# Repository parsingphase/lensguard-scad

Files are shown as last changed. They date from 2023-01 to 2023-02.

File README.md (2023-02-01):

# 3D-printable lens switch guards for various DSLR / Mirrorless camera lenses

[STL](https://en.wikipedia.org/wiki/STL_(file_format)) printable files and [OpenSCAD](https://openscad.org) working files.

Note that these designs are prototypes and have not been used in the field yet.
Also, don't assume that the `.stl` files are correctly updated from the `.scad` files.

## Available guards

STL links will display the file in an interactive viewer.

### Canon RF 800mm f/11 IS STM Lens

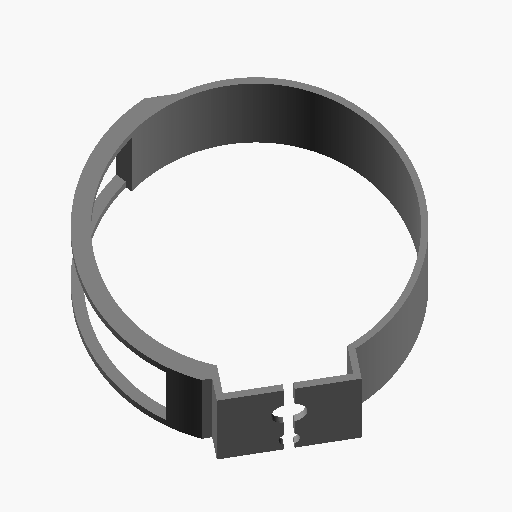
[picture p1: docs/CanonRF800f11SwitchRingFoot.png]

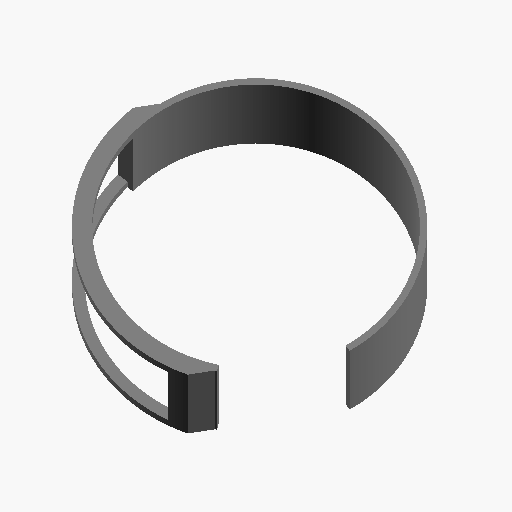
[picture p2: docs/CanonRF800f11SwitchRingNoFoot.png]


This lens has a tripod mounting foot (of sorts) in the same ring segment as the switches.
As such there are two prototypes for this lens, one that omits the foot mounting entirely,
with the intent that it'll be mounted with dual-sided adhesive tape, and one that tries to 
use the foot mount to hold the lens in place. Note that this will interfere with the mount;
best case is you'll likely need a longer mounting screw, worst case is your camera isn't as
secure on your tripod. All use of these designs is at your own risk.

Another fun aspect of this lens is that the ring segment is not flat, so fit is best-effort.

* Mount with foot: [STL](CanonRF800f11SwitchRingFoot.stl), [SCAD](CanonRF800f11SwitchRingFoot.scad)
* Mount without foot: [STL](CanonRF800f11SwitchRingNoFoot.stl), [SCAD](CanonRF800f11SwitchRingNoFoot.scad)

### Sigma 150-600mm f/5-6.3 DG OS HSM Contemporary Lens for Canon EF
### Sigma 100-400mm f/5-6.3 DG OS HSM Contemporary Lens for Canon EF

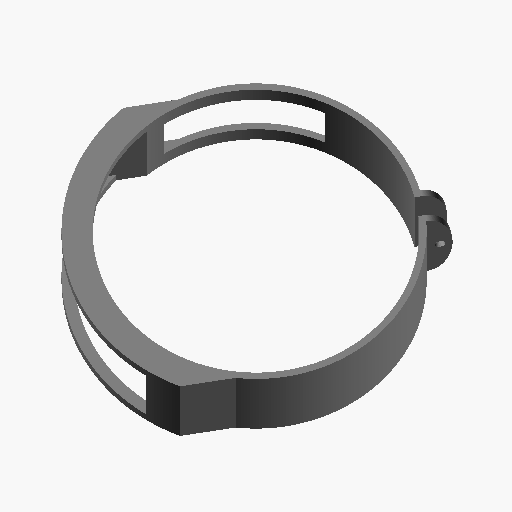
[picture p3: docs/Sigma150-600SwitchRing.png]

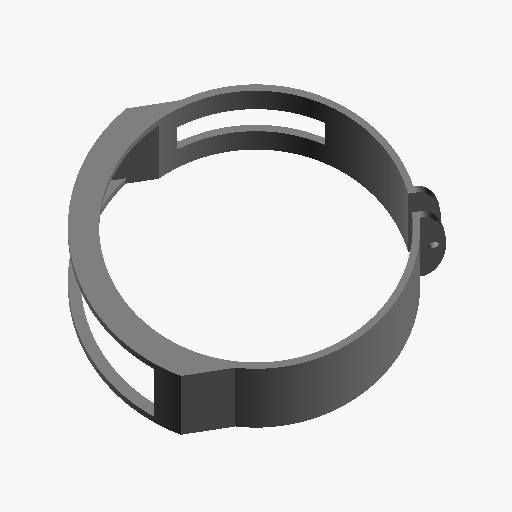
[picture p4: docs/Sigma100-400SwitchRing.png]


These lenses are a very similar design; the lens segments are unobstructed by any foot mount 
and have a flat cross-section. Current designs have a fitting for a #4 closure bolt opposite the switch window.

* 150-600: [STL](Sigma150-600SwitchRing.stl), [SCAD](Sigma150-600SwitchRing.scad)
* 100-400: [STL](Sigma100-400SwitchRing.stl), [SCAD](Sigma100-400SwitchRing.scad)

## Printed rings

Printed in ABS by Taurus 3D via [CraftCloud3D](https://craftcloud3d.com/). I've not fit the other guards yet.

### Canon RF 800mm f/11 IS STM Lens

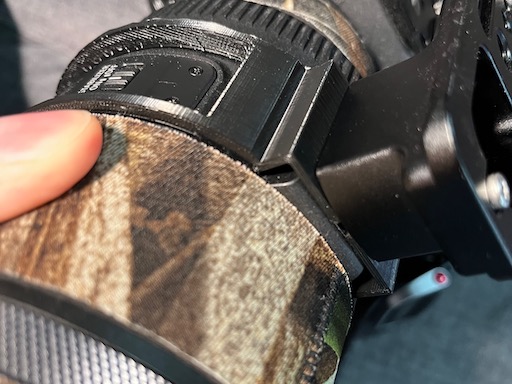
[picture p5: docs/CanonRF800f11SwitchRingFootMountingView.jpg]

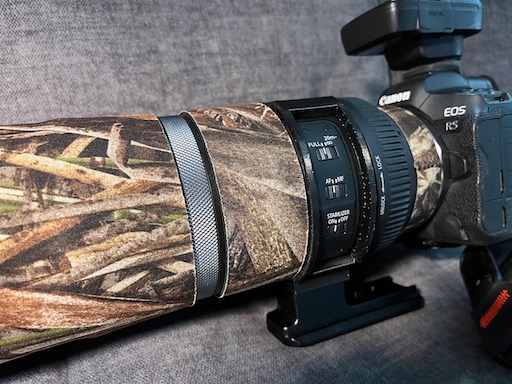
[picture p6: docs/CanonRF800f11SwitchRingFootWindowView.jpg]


### Sigma 150-600mm f/5-6.3 Lens

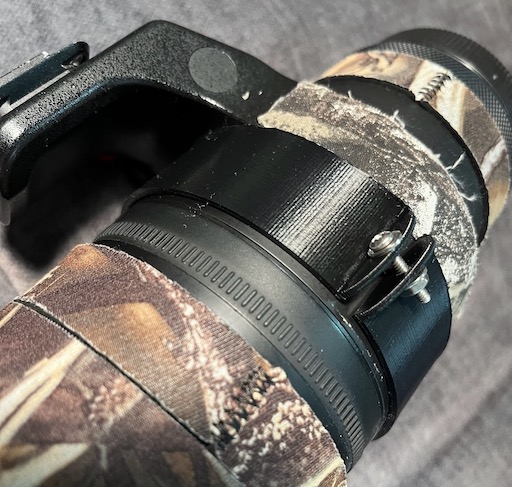
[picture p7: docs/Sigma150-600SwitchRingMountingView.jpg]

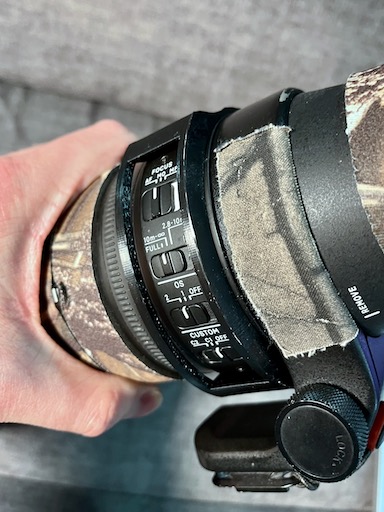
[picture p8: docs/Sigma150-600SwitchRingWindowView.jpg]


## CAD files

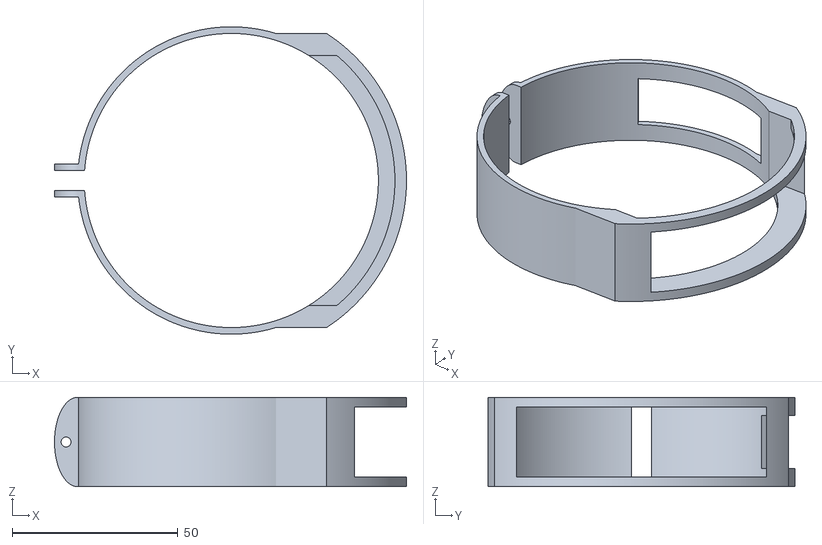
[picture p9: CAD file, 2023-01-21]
Sigma150-600SwitchRing.stl
106.3 x 92.8 x 27.0

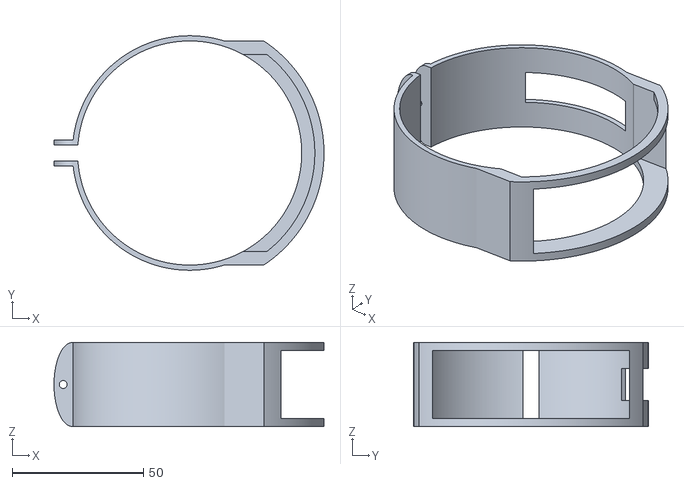
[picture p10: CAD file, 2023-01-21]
Sigma100-400SwitchRing.stl
102.8 x 89.3 x 32.0

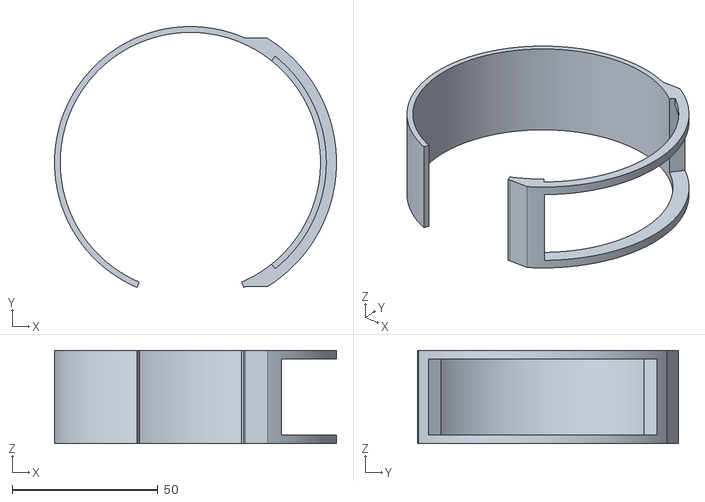
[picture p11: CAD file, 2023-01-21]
CanonRF800f11SwitchRingNoFoot.stl
96.6 x 89.4 x 32.0

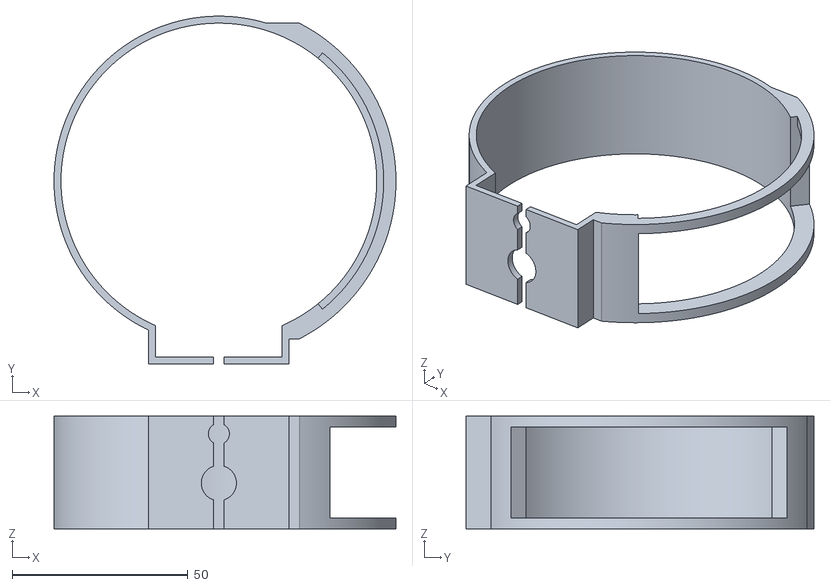
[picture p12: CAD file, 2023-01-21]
CanonRF800f11SwitchRingFoot.stl
97.3 x 98.9 x 32.0

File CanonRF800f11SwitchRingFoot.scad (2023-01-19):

// Switch guard for a Canon RF 800mm f/11 IS STM lens
// Note: this is an untested (unprinted) model

// fine
$fa = 1;
$fs = 0.4;

//fast
//$fa = 2;
//$fs = 5;

// X-axis: towards switches
// Y-axis: away from foot
// Z-axis: towards subject

// Configuration
// units: mm (we can measure this with a flexible tape, easier than measuring diameter or angle)
barrelCircumferenceMeasured = 286; // measured, at peak of rim
//barrelCircumference = 286; // Work for 91mm diameter when closing loop with foot
barrelCircumference = 282; // Work for 90mm diameter when foot has adjustment
switchArc = 80; // 80 by tape at switch surface to base of slope
footOffsetArc = 12; // from end of switches, slope base to slope base
footWidthArc = 36; // slope base to slope base
footSurfaceFromCenter = 95 - (90 / 2);
footPlateThickness = 2; // balance between strength and required screw length

bandWidth = 32; // cylinder height of band; lens segment is 36 mm, minus 3 at back, 1 at front
bandInnerRadius = barrelCircumference / (2 * PI);
bandThickness = 2;
nearSwitchGuardWidth = 3; // how much we leave on the camera side of the cut-out for the switches
farSwitchGuardWidth = 3; // < 0… don't
farSwitchGuardRelief = 2; // space to let us slide the front guard over the switches
// probably only need 2mm farSwitchGuardRelief if measures are valid
shieldThickness = 5; // mm, starts just beyond the inner edge of the band
shieldSquareTrim = - 1; // how far we cut the shield back from being circular; <0 = "don't

bandAdjustmentGap = 3; // How wide a gap to leave in the band to allow tension adjustment, <=0 for none

// Switch ring profile (measured by transfer calipers)
//  TOWARDS SUBJECT (outside is left)
//    / - slope -   91mm, asymmetric
//   | key plateau
//  || switch       92mm (in groove?)  asymmetric, 3mm from valley
//   | key plateau  92mm asymmetric
//    ) valley -    89mm ⌀ symmetric
//   ( rim          91mm ⌀ symmetric                1 mm from valley
//  TOWARDS CAMERA

// With barrelCircumference 286, bandInnerDiameter = 91.0366
// With barrelCircumference 290, bandInnerDiameter = 92.3099

// Possible opportunity to add "spring lever" grippers on inside
// (diagonal, fixed at one end: ト - tricky to print/support?)

// Maths
switchGapAngle = switchArc * (360 / barrelCircumference);
footGapStartAngle = ((switchArc / 2) + footOffsetArc) * (360 / barrelCircumference);
footGapWidthAngle = footWidthArc * (360 / barrelCircumference);
pillarWidthFudge = 8; // increase angle until we don't get a notch when we apply bounding box
shieldEdgeAngle = footGapStartAngle - (switchGapAngle / 2) + pillarWidthFudge; // how wide we want the "pillars"

// Modules
module switchShield() {
  translate([0, 0, - bandWidth / 2])
    rotate(- switchGapAngle / 2 - shieldEdgeAngle)
      rotate_extrude(angle = switchGapAngle + (shieldEdgeAngle * 2))
        translate([bandInnerRadius + 0.5, 0, 0])
          square([shieldThickness, bandWidth]);
}

module switchWindowWedge(xProject = 0, reduceAngle = 0) {
  // gap for switches, wedge version

  switchCutWedgeHeight = bandWidth - (nearSwitchGuardWidth + farSwitchGuardWidth);

  // bottom of our wedge should be on z-plane after extrusion
  // if we move down by (bandWidth / 2), wedge bottom is at ring bottom
  translate([xProject, 0, + nearSwitchGuardWidth - (bandWidth / 2)]) // move down to leave visor space
    rotate(- (switchGapAngle - reduceAngle) / 2)
      rotate_extrude(angle = (switchGapAngle - reduceAngle))
        translate([(bandInnerRadius - xProject) - 0.5, 0, 0])
          square([(shieldThickness) * 1.5, switchCutWedgeHeight]);
}

module switchWindowBox() {
  // gap for switches, box version - not currently used

  switchCutWedgeHeight = bandWidth - (nearSwitchGuardWidth + farSwitchGuardWidth);

  // we only want to span the z-plane if we're assuming symmetry…
  //  translate([0, 0, - switchCutWedgeHeight / 2]) // span z-plane
  // bottom of our wedge should be on z-plane after extrusion
  // if we move down by (bandWidth / 2), wedge bottom is at ring bottom

  slotBoxLength = bandInnerRadius + 2 * shieldThickness;
  slotBoxWidth = 2 * (bandInnerRadius * sin(switchGapAngle / 2));

  translate([0, - slotBoxWidth / 2, + nearSwitchGuardWidth - (bandWidth / 2)]) // move down to leave visor space
    cube([slotBoxLength, slotBoxWidth, switchCutWedgeHeight]);
}

module switchShieldBoundingBox() {
  limiterEdge = (bandInnerRadius + shieldThickness - shieldSquareTrim) * 2;
  fudge = 0; // stop "nicks" at edge of visor
  cube([limiterEdge, bandInnerRadius * 2 - fudge, bandWidth], center = true);
}

module farShieldReliefWedge() {
  // bottom of our wedge should be on z-plane after extrusion
  // if we move down by (bandWidth / 2), wedge bottom is at ring bottom
  translate([0, 0, - farSwitchGuardWidth * 1.5 + bandWidth / 2]) // move down to leave visor space
    rotate(- (switchGapAngle) / 2)
      rotate_extrude(angle = (switchGapAngle))
        square([bandInnerRadius + farSwitchGuardRelief, farSwitchGuardWidth * 2]);
}

module footWindow() {
  // not used with mount
  footCutWedgeHeight = bandWidth * 1.1;
  translate([0, 0, - footCutWedgeHeight / 2]) // span z-plane
    rotate(- footGapStartAngle)
      rotate_extrude(angle = - footGapWidthAngle)
        square([bandInnerRadius * 1.1, footCutWedgeHeight]);
}

module footCutOut() {
  translate([0, - footSurfaceFromCenter / 2, 0])
    cube([footWidthArc, footSurfaceFromCenter, bandWidth * 1.1], center = true);
}

module cylinderCore() {
  cylinder(1.1 * bandWidth, r = bandInnerRadius, center = true);
}

module mainBand() {
  //  difference() {
  cylinder(bandWidth, r = bandInnerRadius + bandThickness, center = true);
  //    cylinderCore();
  //  }
}

module footMountBlock() {
  footMountThickness = (footSurfaceFromCenter + footPlateThickness - bandInnerRadius) * 2;
  translate([0, - bandInnerRadius, 0])
    difference() {
      // foot block main body
      cube([footWidthArc + 2 * footPlateThickness, footMountThickness, bandWidth], center = true);
      union() {
        // Main screw hole
        translate([0, 0, - 3])
          rotate([90, 0, 0])
            cylinder(footMountThickness * 1.1, r = 5, center = true);
        // Main screw should be centered 16 mm from back of lens segment (20 from front)
        // ie 13mm from back edge of band, 19 from front
        // band is 32 (CHECK CHANGES!), so default offset is 16
        // so move 3mm towards back / bottom
        // pin hole
        translate([0, 0, 11])
          rotate([90, 0, 0])
            cylinder(footMountThickness * 1.1, r = 3, center = true);
        // Pin should be 27 mm from back of band (5 from front), so r=3 means thin front band
      }
    }
}

module mainBandGap() {
  if (bandAdjustmentGap > 0) {
    translate([0, - footSurfaceFromCenter - bandThickness / 2, 0])
      cube([bandAdjustmentGap, , 2 * bandThickness, 1.1 * bandWidth], center = true);
  }
}

module subtractor() {
  // gaps / relief:
  union() {
    switchWindowWedge(0, 0);
    //    footWindow();
    footCutOut();
    farShieldReliefWedge();
    cylinderCore();
    mainBandGap();
  }
}

// Assembly
color("gray")
  difference() {
    union() {
      mainBand();
      intersection() {
        switchShield();
        switchShieldBoundingBox();
      }
      footMountBlock();
    }

    subtractor();
  };

//color("green")
//  subtractor();

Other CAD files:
CanonRF800f11SwitchRingNoFoot.scad
Sigma100-400SwitchRing.scad
Sigma150-600SwitchRing.scad

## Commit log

2023-01-07 Rough first concept of a switch guard for the Canon 800mm f/11. Numbers are all guessed.
    [LensRing800Cylinder.scad]
2023-01-07 Revise original design with measured values
    [LensRing800Cylinder.scad]
2023-01-07 Fix maths (radius, not diameter)!
    [LensRing800Cylinder.scad]
2023-01-07 Cut gaps last
    [LensRing800Cylinder.scad]
2023-01-07 Move more features to modules
    [LensRing800Cylinder.scad]
2023-01-07 Modularize further, focus on cutting
    [LensRing800Cylinder.scad]
2023-01-07 Fix wedge offset maths
    [LensRing800Cylinder.scad]
2023-01-07 Support upper & lower guard, still with wedge-shaped window
    [LensRing800Cylinder.scad]
2023-01-07 Move to rectilinear slot for switches
    [LensRing800Cylinder.scad]
2023-01-07 Composite switch slot
    [LensRing800Cylinder.scad]
2023-01-07 Tweaks; don't add bottom guard without offset
    [LensRing800Cylinder.scad]
2023-01-07 Add lower guard relief - clumsy corner with composite window
    [LensRing800Cylinder.scad]
2023-01-07 Swap back to a wedge window - simpler for lower guard offset, fewer nooks.
    [LensRing800Cylinder.scad]
2023-01-07 Cleanup, remove un-needed ceil() calls
    [LensRing800Cylinder.scad]
2023-01-08 As printed 2023-01-07
    [LensRing800Cylinder.scad, LensRing800Cylinder.stl]
2023-01-12 800mm lens measurement notes
    [LensRing800Cylinder.scad]
2023-01-18 Refactor prototype one such that broader shield is at natural bottom edge
    - Reduces amount of scaffolding needed to support "top" (now narrow) shield
    [LensRing800Cylinder.scad, LensRing800Cylinder.stl]
2023-01-18 Fit to inner radius, clamp-style
    [LensRing800Cylinder.scad, LensRing800Cylinder.stl]
2023-01-18 Revise terminology to near/far as shields may be of same width
    [LensRing800Cylinder.scad]
2023-01-18 Rename base files prior to adding option with foot
    [CanonRF800f11SwitchRingClamp.scad, CanonRF800f11SwitchRingClamp.stl, LensRing800Cylinder.stl]
2023-01-18 Add foot mount (WIP)
    (needs mount holes, reduce plate thickness)
    [CanonRF800f11SwitchRingFoot.scad]
2023-01-18 First draft with foot mount
    [CanonRF800f11SwitchRingFoot.scad, CanonRF800f11SwitchRingFoot.stl]
2023-01-19 Manually tweak pillar width to avoid weak nicks
    [CanonRF800f11SwitchRingFoot.scad, CanonRF800f11SwitchRingFoot.stl]
2023-01-19 First draft Sigma 600 ring
    [Sigma150-600SwitchRing.scad]
2023-01-19 Revise Sigma 600 to cuboid switch window
    [Sigma150-600SwitchRing.scad]
2023-01-19 Add Sigma 600 STL
    [Sigma150-600SwitchRing.stl]
2023-01-19 Add an adjustment gap to the band
    [Sigma150-600SwitchRing.scad, Sigma150-600SwitchRing.stl]
2023-01-19 Add an adjustment gap in the foot
    [CanonRF800f11SwitchRingFoot.scad, CanonRF800f11SwitchRingFoot.stl]
2023-01-19 Tweak measurements for tighter ring using foot gap for relief
    [CanonRF800f11SwitchRingFoot.scad, CanonRF800f11SwitchRingFoot.stl]
2023-01-20 Add 100-400 ring
    [Sigma100-400SwitchRing.scad, Sigma100-400SwitchRing.stl]
2023-01-20 First draft screw closure mount on 600mm lens
    [Sigma150-600SwitchRing.scad, Sigma150-600SwitchRing.stl]
2023-01-20 Clean up maths around screw closure holes
    [Sigma150-600SwitchRing.scad, Sigma150-600SwitchRing.stl]
2023-01-20 Add closure screw mount to 400mm
    [Sigma100-400SwitchRing.scad, Sigma100-400SwitchRing.stl, Sigma150-600SwitchRing.scad]
2023-01-20 Add README
    [CanonRF800f11SwitchRingNoFoot.scad, CanonRF800f11SwitchRingNoFoot.stl]
2023-01-21 Increase band gap for screw closure, fix README order
    [Sigma100-400SwitchRing.scad, Sigma100-400SwitchRing.stl, Sigma150-600SwitchRing.scad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]
2023-01-21 Add command-line build script to enable "in-case" export of latest SCAD files
    [CanonRF800f11SwitchRingFoot.stl, CanonRF800f11SwitchRingNoFoot.stl, Sigma100-400SwitchRing.stl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]
2023-01-21 Update docs with auto-rendered images
    [CanonRF800f11SwitchRingFoot.stl, CanonRF800f11SwitchRingNoFoot.stl, Sigma100-400SwitchRing.stl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]
2023-02-01 Add photos of printed guards
